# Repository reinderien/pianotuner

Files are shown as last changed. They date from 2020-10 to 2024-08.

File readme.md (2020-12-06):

# Custom Piano Tuner

## Environment

### apt packages

- libasound2-dev (for compilation only)
- libasound2 - underlying ALSA support
- linux-libc-dev - Linux headers for SPI

Remove pulseaudio.

Todo: move to headless mode and blow away a pile of unneeded packages.

### /boot/config.txt

```
# See https://rpf.io/configtxt
dtparam=spi=on

dtoverlay=spi0-1cs

arm_64bit=1

# todo: turn off video
```

### Audio USB device details

`dmesg`:

```
usb 1-1.2: new full-speed USB device number 3 using xhci_hcd
usb 1-1.2: New USB device found, idVendor=0d8c, idProduct=013c, bcdDevice= 1.00
usb 1-1.2: New USB device strings: Mfr=1, Product=2, SerialNumber=0
usb 1-1.2: Product: USB PnP Sound Device
usb 1-1.2: Manufacturer: C-Media Electronics Inc.      
input: C-Media Electronics Inc.       USB PnP Sound Device as /devices/platform/scb/fd500000.pcie/pci0000:00/0000:00:00.0/0000:01:00.0/usb1/1-1/1-1.2/1-1.2:1.2/0003:0D8C:013C.0001/input/input0
hid-generic 0003:0D8C:013C.0001: input,hidraw0: USB HID v1.00 Device [C-Media Electronics Inc.       USB PnP Sound Device] on usb-0000:01:00.0-1.2/input2
```

`lsusb`:

```
Bus 001 Device 003: ID 0d8c:013c C-Media Electronics, Inc. CM108 Audio Controller
```

`arecord -l`:

```
**** List of CAPTURE Hardware Devices ****
card 1: Device [USB PnP Sound Device], device 0: USB Audio [USB Audio]
  Subdevices: 1/1
  Subdevice #0: subdevice #0
```

`arecord -L`:

```
default:CARD=Device
    USB PnP Sound Device, USB Audio
    Default Audio Device
sysdefault:CARD=Device
    USB PnP Sound Device, USB Audio
    Default Audio Device
hw:CARD=Device,DEV=0
    USB PnP Sound Device, USB Audio
    Direct hardware device without any conversions
plughw:CARD=Device,DEV=0
    USB PnP Sound Device, USB Audio
    Hardware device with all software conversions
```

Examine these lines in `/usr/share/alsa/alsa.conf`; the defaults should
correspond to the correct card and device listed above:

```
defaults.ctl.card 1
defaults.pcm.card 1
defaults.pcm.device 0
defaults.pcm.subdevice 0
```

### Audio input test

```
$ arecord -D hw:CARD=Device,DEV=0 -c 1 -f S16_LE -r 48000 -d 1 -v output-test
Recording WAVE 'output-test' : Signed 16 bit Little Endian, Rate 48000 Hz, Mono
Hardware PCM card 2 'USB PnP Sound Device' device 0 subdevice 0
Its setup is:
  stream       : CAPTURE
  access       : RW_INTERLEAVED
  format       : S16_LE
  subformat    : STD
  channels     : 1
  rate         : 48000
  exact rate   : 48000 (48000/1)
  msbits       : 16
  buffer_size  : 24000
  period_size  : 6000
  period_time  : 125000
  tstamp_mode  : NONE
  tstamp_type  : MONOTONIC
  period_step  : 1
  avail_min    : 6000
  period_event : 0
  start_threshold  : 1
  stop_threshold   : 24000
  silence_threshold: 0
  silence_size : 0
  boundary     : 1572864000
  appl_ptr     : 0
  hw_ptr       : 0
```

### Verifying SPI

```
$ raspi-gpio get | grep SPI0
GPIO 9: level=0 fsel=4 alt=0 func=SPI0_MISO pull=DOWN
GPIO 10: level=0 fsel=4 alt=0 func=SPI0_MOSI pull=DOWN
GPIO 11: level=0 fsel=4 alt=0 func=SPI0_SCLK pull=DOWN
```

```
$ lsmod | grep spi
spidev                 24576  0
spi_bcm2835            24576  0
```

```
$ ls -l /dev/spi*
crw-rw---- 1 root spi 153, 0 Dec  5 17:06 /dev/spidev0.0
```

```
# First, guarantee sync; this requires at most two bytes
echo -ne "\x00\x00" > /dev/spidev0.0

# Channel 1: 1V, 205: 0b001_000_00 0b1100_1101
echo -ne "\x20\xCD" > /dev/spidev0.0

# Channel 2: 2V, 410: 0b010_000_01 0b1001_1010
echo -ne "\x41\x9A" > /dev/spidev0.0

# Channel 5: 3V, 614: 0b101_000_10 0b0110_0110
echo -ne "\xA2\x66" > /dev/spidev0.0

# Channel 4: 4V, 26, 0b100_11001
echo -ne "\x99" > /dev/spidev0.0
```

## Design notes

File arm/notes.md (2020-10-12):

## Hardware

The RPI 4 has a:
 
- BCM2711: Quad-core Cortex-A72 ARM v8-A 64-bit (Requires upgrading from
  Raspbian for 64-bit support)
- NEON SIMD extensions are mandatory per core
- VFPv4 Floating Point Unit onboard (per core)
- 32 64-bit FPU registers
- fused multiply-accumulate instructions

## Math

                          N-n-1
We need to compute r(n) = sum_k x(k)*x(k + n)
                          k=0

As the dot product,

    r(n) = x[0:N-n] dot x[n:N]

If there are 2048 samples, an S16 will overflow if the mean is above

    sqrt(2^15 / 2048) = 4

so it can't be done in-place. An equivalent S32 won't overflow until a mean of

    sqrt(2^31 / 2048) = 1024

but overflow becomes a non-issue for BLAS, which requires floats.

## BLAS

We aren't using anything in GSL that BLAS doesn't already have, so use the
latter. The input type is float. The output type can be float or double.

For the dot-product method, vectors will be aliased (overlap). GSL says:

> If the arguments will not be modified (for example, if a function prototype 
> declares them as const arguments) then overlapping or aliased memory regions 
> can be safely used.

BLAS "scalar" dot product is level 1 (vector*vector); we have to loop N times
calling `cblas_sdot` and offsetting the second vector every time.

Level 2 (matrix*vector) would use an "anti-triangular" matrix that is symmetric,
calling `cblas_ssymv`. Unfortunately `lda` does not permit row pitch hacks that
would allow us to reuse a single vector.

Alternatively, for the reversed-triangular case, we could use `cblas_strmv`, but
the same pitch restriction applies. This means that we can't have a row-aliased
matrix, because it doesn't use array-of-array format; it uses a contiguous 
block.

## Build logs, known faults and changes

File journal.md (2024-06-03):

### Dec 20, 2015

I started a rudimentary, software-only piano tuner experiment.

### Dec 21, 2015

Abandoned the software experiment.

### July 4, 2019

I hack together some notes for a possible hardware implementation of a piano
tuner, thinking about:

- Needles for octave, note in octave, tuning in note, volume
- Lamp for power
- Lamps behind needle dials
- Capacitive fade-in for lamps
- Glass or plastic bead in front of power lamp
- Phonograph-style mic pickup
- Clock hands for needles

Initially I assume it'll run a Fast Fourier Transform, and toy with the idea
of using a 
[Texas Instruments LEA](https://www.ti.com/lit/an/slaa720/slaa720.pdf)
(Low-Energy Accelerator). That would be good if we're making 10,000 of these
things, but it would be a steep learning curve.

All of this goes into a Google Doc and then somewhat forgotten about.

### Sept 26, 2020

I found an antique-style wooden box on Facebook Marketplace. It's pretty
clearly one-of-a-kind, and was hand-made in an Egyptian workshop by a late 
relative of the seller. It's perfect.

In around now, plotting starts to solidify for a hardware tuner.

### Sept 28, 2020

Wife orders 
[copper foil](https://www.amazon.ca/gp/product/B0042SWYUA) 
for the horn. I order the 
[USB microphone](https://www.amazon.ca/gp/product/B07VWJ1XB2) 
that will be connected to the Raspberry Pi 4 I have on hand.

### Sept 29, 2020

Orders for more power accessories:
[5V 25W power supply](https://www.amazon.ca/gp/product/B00DECXUD0), 
and a nice little 
[USB-C-to-terminal-block power adapter](https://www.amazon.ca/gp/product/B07R8YPFD7)
to power the Pi without having to jankily connect a cell phone charger on the
inside of the enclosure.

Ordered a handful of gauges, 5Vdc analogue, of various sizes:

[45mm](https://www.ebay.ca/itm/181981812727),
[66mm](https://www.ebay.ca/itm/183445575857)
and
[90mm](https://www.ebay.ca/itm/172695600128).

These are coming from China so I'm expecting it to take forever for them to 
get here, but anything in North America is exhorbitant. The intent is to 
replace the faceplate with a custom one and backlight it if possible.

Order some vintage-style electrical accessories from 
[Vintage Wire & Supply](https://vintagewireandsupply.com). They're relatively
expensive but look incredible.

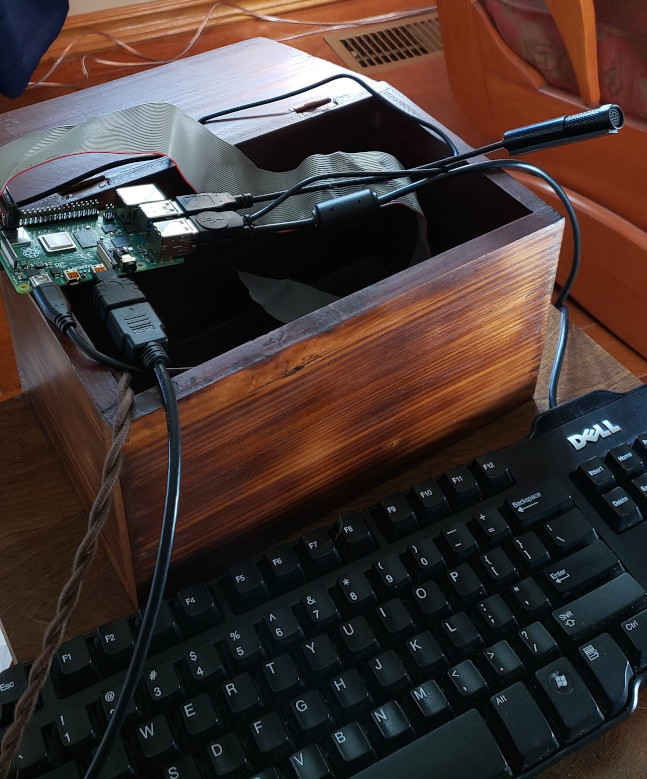
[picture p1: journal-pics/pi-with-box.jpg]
Raspberry Pi sitting outside of the box


Pictured above: temporary keyboard on the bottom; open box (so far unmodified) 
in the middle with the Raspberry Pi board sitting on top of it; USB microphone 
sticking out to the right. The ribbon cable is for a real-time clock that is 
also temporary. On the left you can see the twisted brown cotton vintage-style 
120VAC cord.

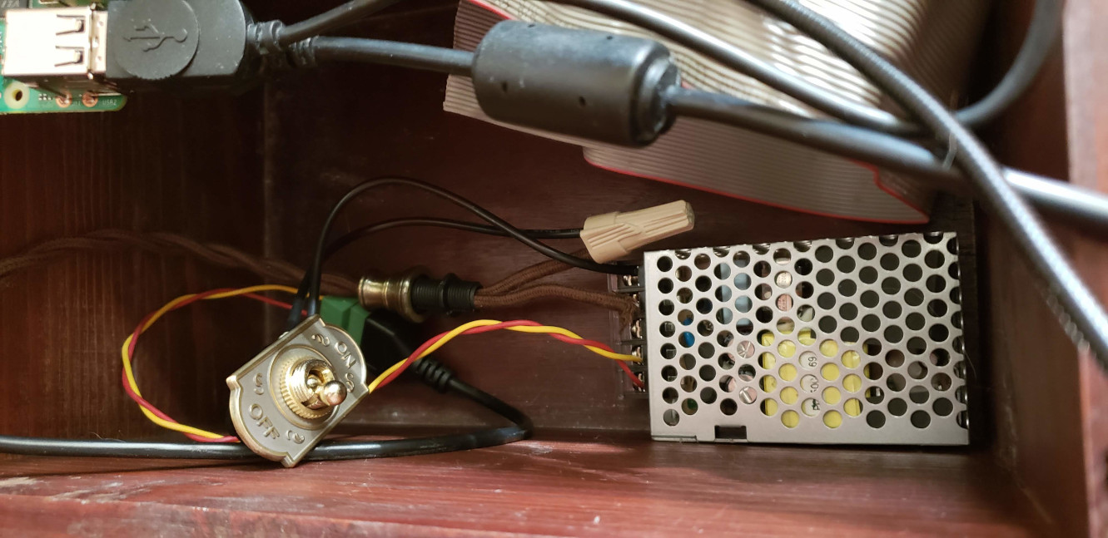
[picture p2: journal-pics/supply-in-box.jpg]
Power components sitting in box


Pictured above: power components sitting in a temporary arrangement in the box. 
Far centre left is the brown 120VAC cord, running to a brass stress relief in 
the middle that will eventually be in the side of the box. Centre is a white 
marette to the switch. Lower left is the antique switch that will be mounted to 
the exterior of the box. Lower right is the MeanWell power supply; more rugged 
and well-ventilated than the typical cell phone charger. The red-yellow cord 
runs 5V from the power supply to a small green terminal block, in turn through a 
USB-C cable to the Raspberry Pi on the upper left.

### Oct 2, 2020

Going on vacation. The wife has let me bring a pile of tech goodies to work on 
this project.

### Oct 3, 2020

Using the same GitHub web page, resuscitate the tuner project, but with 
hardware in mind. The Raspberry Pi, keyboard, mouse, microphone and cell phone
power supply are set up on the coffee table of the cottage, and I have a great
time getting going on development.

### Oct 4, 2020

Start using the Simple Direct Layer for microphone capture on the Raspberry Pi.
Pretty much immediately throw that out the window in favour of the underlying
Advanced Linux Sound Architecture.

### Oct 7, 2020

Research into the best way to detect pitch. Intend on running autocorrelation 
for note detection, in line with the
[findings of Coert Vonk](https://coertvonk.com/sw/embedded/arduino-pitch-detector-13252),
and associated research by
[Brown](http://academics.wellesley.edu/Physics/brown/pubs/acptrv89P2346-P2354.pdf)
and
[Monti](http://193.166.3.2/pub/sci/audio/dafx/2000/profs.sci.univr.it/%257Edafx/Final-Papers/pdf/Monti_DAFX00poster.pdf).

Some of it makes no sense to me so I post on a 
[Digital Signal Processing](https://dsp.stackexchange.com/questions/70736)
forum.

Ordered some Microchip PIC16LF1773 (programmable interrupt controller) from 
Mouser, since DigiKey was nearly out of stock. These devices have a mix of 5- 
and 10-bit unbuffered DACs that can be internally buffered with three op-amps; 
they also support UART, I2C and SPI - so one way or the other they'll 
definitely be able to talk with the Pi.

### Oct 10, 2020

Start using the Gnu Scientific Library with the intent of applying it to the 
autocorrelation work.

### Oct 11, 2020

Throw GSL out the window in favour of ATLAS (Automatically Tuned Linear Algebra 
Software), an implementation of BLAS (Basic Linear Algebra Subprograms).

### Oct 16, 2020

The gauges arrived from China, quicker than I expected! They're wonderful
little devices, fully disassemble-able with two screws on the side, and come
pre-packaged with hardware for the mounting bolts. There's a high-accuracy
resistor in each, and the input impedance is a little over 5k, so the PIC can
definitely handle it.

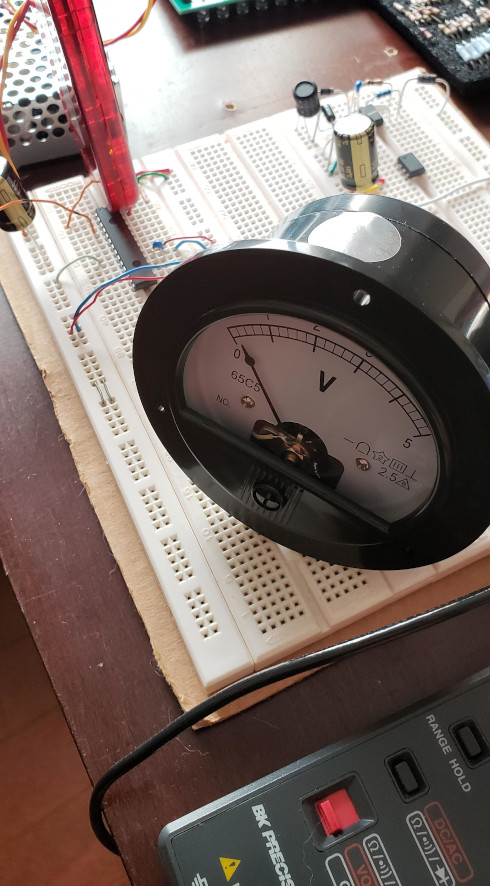
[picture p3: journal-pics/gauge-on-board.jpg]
Gauge sitting on a breadboard


Upper left: chassis of the power supply; with the red PICkit 3 programmer in 
front of it, plugged into the breadboard.

The breadboard has the intended DAC PIC just below the PICkit.

On the gauge itself: the sticker on the top will be discarded; the front 
plastic pane and surrounding cylindrical cover come off with two screws on the 
side (not shown); then the instrument plate comes off with two bolts on the 
front.

### Oct 19, 2020

Start a PIC firmware project to act as a DAC (digital-to-analogue converter) 
for the Raspberry Pi.

### Oct 21, 2020

Start an Eagle schematic to plan out how the DAC will be connected.

### Oct 22, 2020

Parts I still need to dig up or buy:

- Amber LEDs for the gauge backlights
- Perfboard
- Rectangular cable to run from the Pi to header on the perfboard
- A rail-to-rail 0-5V buffer op-amp for the one remaining unbuffered DAC output

I also need to upgrade the Pi to a 64-bit operating system, since I didn't 
realize I had been using a deprecated 32-bit Raspbian.

Also need to write a calibration routine that gives me interquartile range for
the harmonics at various notes.

### Oct 23, 2020

Consider using a nice amber LED for backlights; such as the Lite-On LTL-1CHA with
- 3mm diffusion lens
- 20mA max, 2.1 volts forward
- 60° half-power angle
- Wavelengths: 602 nanometres dominant, 610 nanometres peak

If we use 10mA, we need 270R limiting each LED. For fade-in with a capacitor 
parallel to the LED, and a time constant over 2 seconds, we need a large 
capacitor of ~10mF.

### Oct 24, 2020

The capacitive fade-in option kind of sucks. The capacitors needed are big and 
expensive, and all four could be replaced with a single 40mA MOSFET driven by
PWM from the PIC. Another advantage of PWM would be that it works right away,
where as capacitive charge has to go through a dead zone where the forward 
voltage is below that needed by the LED.

The PIC16F1773 supports 10/16-bit hardware PWM with a bunch of different 
sources. PWMs 3, 4, 5, 6, 9 and 11 all support PPS and at least one of them can
output to each of PORTA/B/C, respectively. Compare/capture/PWM (CCP) modules
1, 2, and 7 likewise can output to at least one of those ports.

The hardware solution would have charged by

    V(t) α 1 - exp(-t/𝜏)
    
with 90% by

    t = -𝜏 ln(1 - 0.9)

If we want 90% in two seconds, 𝜏 ~ 0.8686, and our time expression becomes

    V(t) α 1 - 0.1^(t/2)

A piecewise linear approximation would depend on the derivative:

    dV/dt = 1/𝜏 exp(-t/𝜏)
          = -ln0.1 / 2 * 0.1^(t/2)
    
If we increment 8 of the 16 bits in the duty cycle for a PWM,
the configuration would be

    EN = 1
    MODE = 00 (standard)
    PRIE = 1 (interrupt on period match to update duty)
    PS set to divide between 2^0 and 2^7
    CS either HFINTOSC (16MHz) or LFINTOSC (31kHz) - both sleep-compatible
    OFM = 00 (independent run)

We will be starting DC at 0, DC delta at a high value, and applying a simple
binary exponential decay algorithm on the delta. To find the initial delta
value we need to work backward: at the end of the curve, the delta will only
be 1, representing 2^-8 of full deflection. The last intersection of the exact
and approximate curves is at

    -𝜏 ln(2^-8) ~ 4.817 s
    
At this time, the derivative is

    1/𝜏 * 2^-8 ~ 0.004497

The time it takes to increase 2^-8 is, with an initial tangent,

    2^-8 𝜏 exp(t/𝜏)

which starts as 3.4 ms. If we only did this for one cycle, we could still have
a PWM rate of 295 Hz. Assuming a PR of 0x100, 

    Period = (PWMxPR + 1) * prescale / clock
    prescale = log(16e6 * 2^-8 𝜏 / (2^8 + 1)) / log(2) ~ 7.72 > 7

The slowest prescale for 16-bit PWM is 2^7, which would mean a period value of

    2^-8 𝜏 * 16e6 / 2^7 - 1 ~ 423 > 2^8

which would require carry operations during PWM update. If we go the other way,
disable the prescaler and use LFINTOSC=31kHz,

    2^-8 𝜏 * 31e3 - 1 = 104

`TMR2IE` probably won't work in 10-bit mode, because the timer is cleared on
period match.

It's also worth noting that the transfer function for duty cycle to lumens is 
assumed to be linear but probably isn't.

### Oct 25, 2020

Some of the above will stay true and some won't. The problem with having a
fixed delta update rate is that eventually, the delta would need to be
fractional, and we're only using integer math.

This is a very powerful device; we could pursue any of the following as
alternatives:

- Use 16-bit PWM, interrupt on `PRIF`, increment a soft post-scaler,
  increment `PWMxDC` on post-scale overflow, double post-scale factor every
  140 `PRIF`s
- Use 10/16-bit PWM, short `PWMx` output to `TMR4_clk` input, increment 
  `PWMxDCH` on every `TMR4IF`, short `PWMx` output to `TMR6_clk` input, double 
  `PR4` on every `TMR6IF`
- Use CLC with two internal PWM/CCP inputs, offset by a beat frequency
- Use COG with two internal PCM/CCP inputs, offset by a beat frequency

For the last one, we'd have:

- `COG1CON0`
    - `EN` = 1
    - `CS` = 0b10 (HFINTOSC, sleep-compatible)
    - `MD` = 0b000 (steered PWM)
- `G1RIS9` = 1 (PWM5 for rising)
- `G1FIS10` = 1 (PWM6 for falling)
- `COG1STRA` = 1 (output on steering channel A)

### Oct 27, 2020

Continuing the silliness above, I've posted a 
[detailed solution](https://electronics.stackexchange.com/a/529533/10008).

### Nov 24, 2020

A month, more math and experimentation later, the LED fader is done. As it turns 
out, the luminosity transfer function seems to be visually exponential so I can 
get away with a linear ramp. 

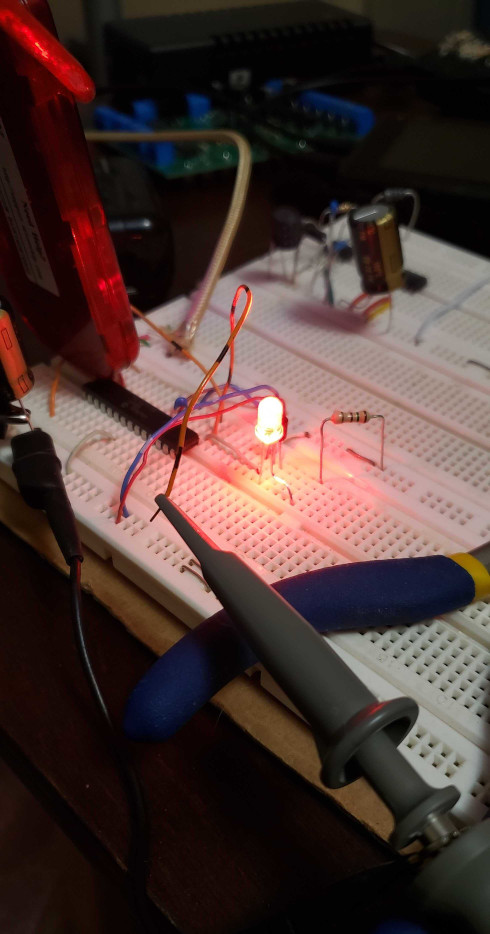
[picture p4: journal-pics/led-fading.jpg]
bright LED


The very bright red LED used in this test will not be used in the final system 
but is working fine nevertheless. This one is so bright that it illuminates my 
ceiling at 20mA.

### Nov 25, 2020

New parts ordered: 

- the protoboard where stuff will get soldered (though-hole only), 
- the nice amber LEDs, 
- some rectangular cables for SPI, and 
- some rail-to-rail operational amplifiers - only one is needed as a buffer for 
  a digital-to-analog converter output; the other outputs have buffers already.

### Nov 26, 2020

Did a rough layout of the digital-to-analog converter circuit as it will be on
the protoboard.

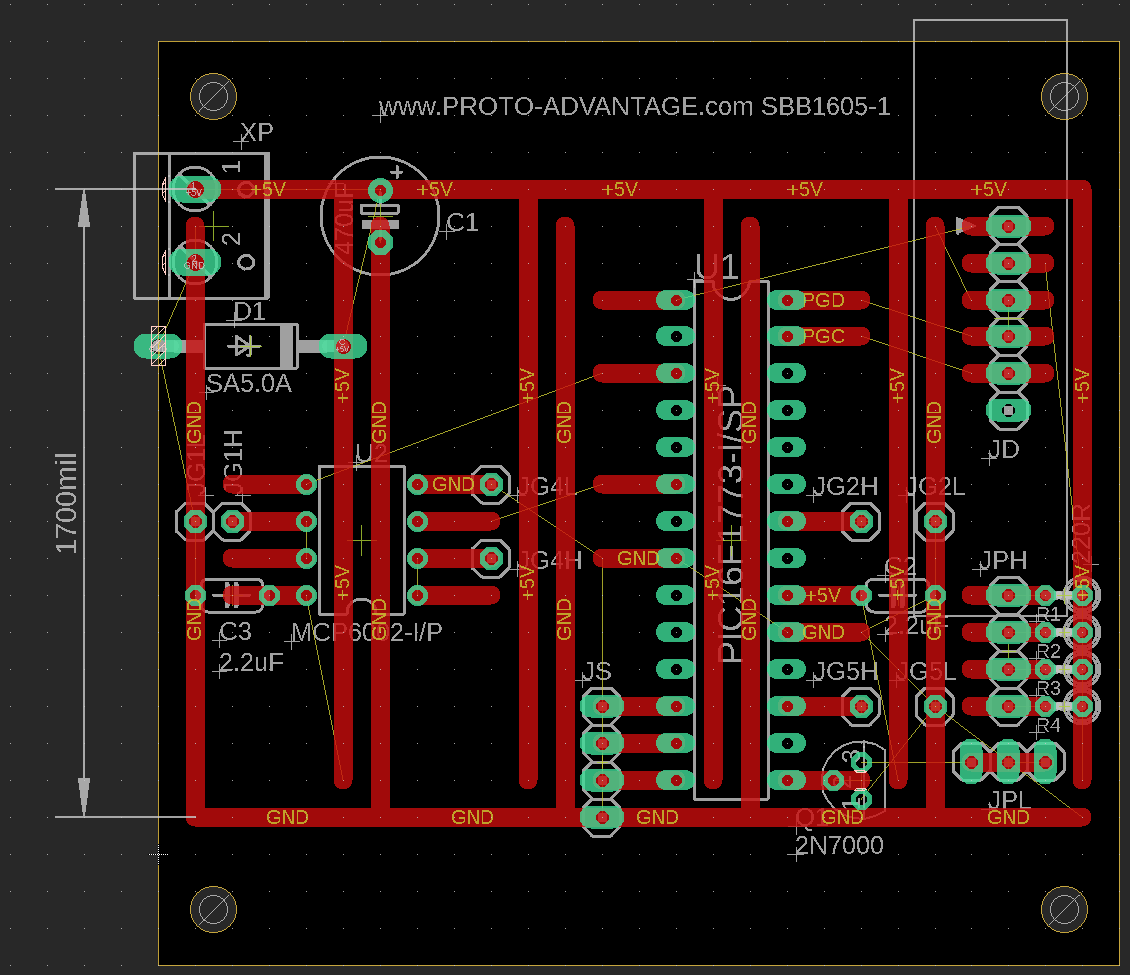
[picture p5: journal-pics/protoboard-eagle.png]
Eagle protoboard layout


- Upper left: the power entry block
- Mid-left: the buffer chip "U2" for gauges. Only one of the two channels is 
  strictly necessary, but use both to offload a tiny bit more current from the 
  MCU and prevent floating.
- Centre: the MCU (microcontroller) "U1" that the Raspberry Pi will talk to, 
  with its SPI (serial port) "JS" on the bottom.
- Lower-right: gauge backlight PWM driving circuit, four-channel
- Upper-right: programming/debug connector "JD".

The red traces are copper on the board's top layer. The thin yellow lines are
ratsnest that I need to wire and solder myself.

### Nov 30, 2020

This `efind` script shows that it's possible to null a fixed, positive offset 
voltage on the MCP6002 operational amplifier I use for DAC buffering.

```python
    Vdd = 5
    Voff = 4.5e-3
    R2 = 0

    def find_r4(R6: float, R5: float, R1: float) -> float:
        return (R5/R6 + 1) * R1 * Voff/Vdd

    def find_r3(R6: float, R5: float, R1: float, R4: float):
        R4R3 = R5/R6 - R4/R1
        if R4R3 == 0:
            return float('inf')
        return R4 / R4R3

    def find_vo(Vi: float, R6: float, R5: float, R1: float, R4: float, R3: float) -> float:
        Vin = Vi*R6/(R6 + R5) + Voff
        I3 = Vin/(R2 + R3)
        I1 = (Vdd - Vin)/R1
        I4 = I3 - I1
        Vo = Vin + R4*I4
        return Vo

    s = Solver(
        (
            Resistor('6', E24, None, 1e6, 10e6),
            Resistor('5', E96, None, 1e3, 10e3),
            Resistor('1', E96, None, 1e6, 10e6),
            Resistor('4', E96, find_r4),
            Resistor('3', E96, find_r3),
        ),
        (
            Output(
                'Vol', 'V', 0,
                partial(find_vo, 0),
            ),
            Output(
                'Voh', 'V', Vdd,
                partial(find_vo, 5),
            ),
        ),
        1e-5,
    )
    s.solve()
    s.print()
```

It outputs:

```
    R6      R5      R1      R4      R3        Vol      Err        Voh      Err
1.5 MΩ 4.42 kΩ 1.13 MΩ 1.02 kΩ  499 kΩ  -13.99 nV -1.4e-08    5.000 V  3.7e-07
1.6 MΩ 6.49 kΩ 1.87 MΩ 1.69 kΩ  536 kΩ  -461.3 nV -4.6e-07    5.000 V  1.9e-06
1.0 MΩ 10.0 kΩ 1.00 MΩ   909 Ω  100 kΩ  -4.500 nV -4.5e-09    5.000 V -5.0e-06
1.0 MΩ 10.0 kΩ 10.0 MΩ 9.09 kΩ 1.00 MΩ  -4.500 nV -4.5e-09    5.000 V -5.0e-06
```

But I won't actually do this nulling, for reasons listed
[here](https://electronics.stackexchange.com/questions/534855).

### December 4, 2020

When my brothers play Path of Exile with me, they have taken to calling its
[crafting workbench](https://pathofexile.gamepedia.com/Crafting_Bench) "[my]
actual workbench" due to its electrified animations. Currently, on the first
day of my latest vacation, my mobile workbench looks like this:

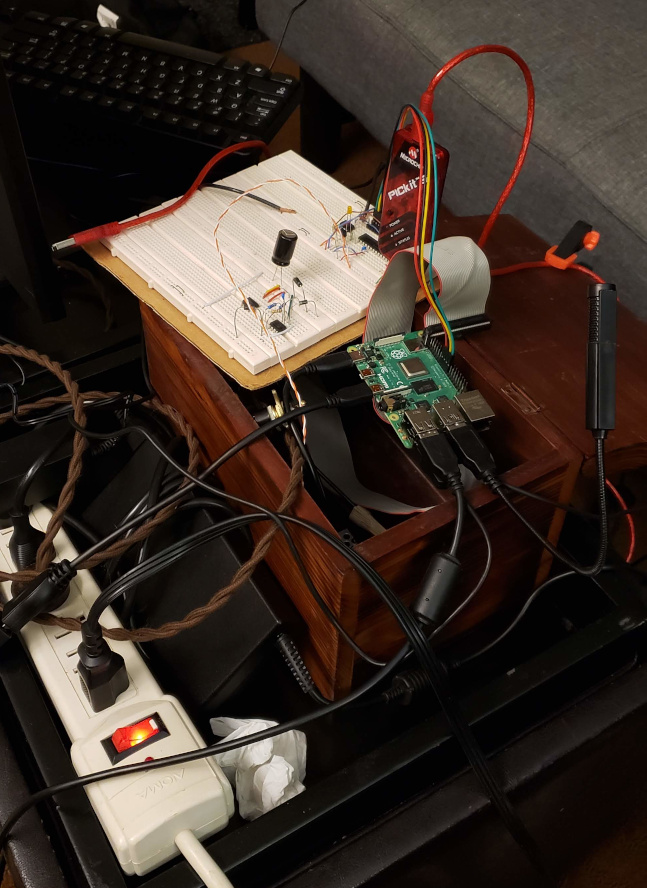
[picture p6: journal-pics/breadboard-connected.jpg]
Breadboard connected


This marks the first time that the breadboard is connected to the Pi via a 
4-conductor wire carrying SPI. The SPI microcontroller firmware was written
last weekend but hasn't been tested yet. The buffer op-amp is connected and
initial gauge tests work. The gauge input posts are left-negative, right-
positive when looking from the front.

I've also (finally) started using a 64-bit OS for the Raspberry Pi 4.

Next is to:

- based on the 
  [documentation](https://www.raspberrypi.org/documentation/hardware/raspberrypi/spi/README.md#software),
  put the SPI module in 8-bit, `SPI_NO_CS` mode
- work off of the Raspberry Pi/Linux
  [SPI test code](https://github.com/raspberrypi/linux/blob/rpi-5.4.y/tools/spi/spidev_test.c)
  
### December 5, 2020
  
If I end up adding a back-illuminated bead for power indication (which now
seems a little redundant to me given that the gauges are already illuminated
on power), one option if I can't find anything better is this thing from
Michael's:

- Item [10402037](https://canada.michaels.com/en/bead-gallery-crystal-faceted-glass-round-beads-18mm/10402037.html)
- 18mm diameter faceted glass
- It's labelled "crystal", though I don't know how far to trust that
  
A very attractive option from the Bead Boutique is their
[quartz "nuggets"](https://thebeadboutiqueon.com/products/22x15mm-faceted-quartz-nugget-beads):

- Natural clear quartz
- 22x15mm "medium focal" size

As for gauge illumination, the LTL-1CHA is way (way, *way*) too dim to be
useful for backlighting. On the next DigiKey order I'll be switching to high-
brightness amber LEDs from Cree. Looking at the gauge interior again, it does
look like a LED mounted at the inner rear of the gauge would need an eyeballed
30 degrees to either side, or 60 degrees total, without some other diffusion
scheme.

### December 12, 2020

The woodworking portion began. I sought some external expertise from my parents
about the best way to cut circular holes for the gauges. I had started with a
drill and then (massive) reciprocating saw, not realizing that we have a jigsaw
("autoscroller") better-suited to the job. All of the gauge holes were then done
by drill, jigsaw, and then dremel sanding to creep up to a snug fit.

The first (gnarly) cuts:

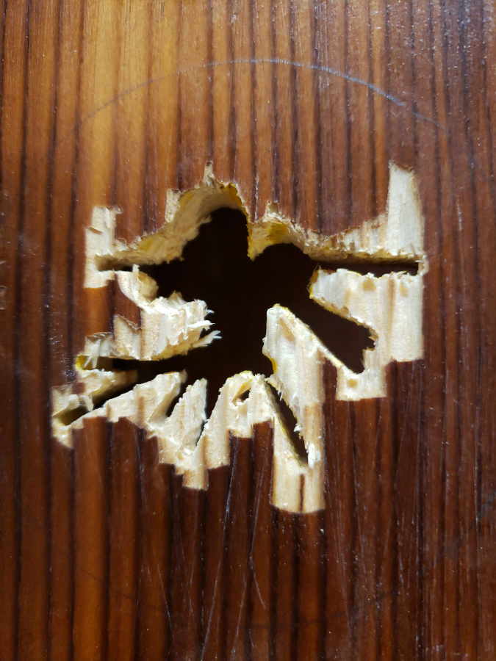
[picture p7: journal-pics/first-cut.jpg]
First cut


This was time-consuming but straightforward. The rear power intake stress relief
was also straightforward. The power indicator was especially lucky: the quartz
teardrop, on its end, fits very well into a hole made by a standard drillbit and
is so snug that it probably won't require glue.

The biggest problem was the power switch. The threaded shaft was too short
compared to the thickness of the wood. A fancy solution would be to recess the
front plate, but I'm not good enough to do that and anyway it wouldn't look as
good as the alternative: ablate a hole for the switch body on the inside of the
box. Given that the box is already assembled and I refuse to disassemble it,
this was a huge pain in the ass and required many passes with an awkwardly-
angled dremel. I got it down to the point where there was barely enough thread
protruding for the front finishing nut to grab, and: good enough.

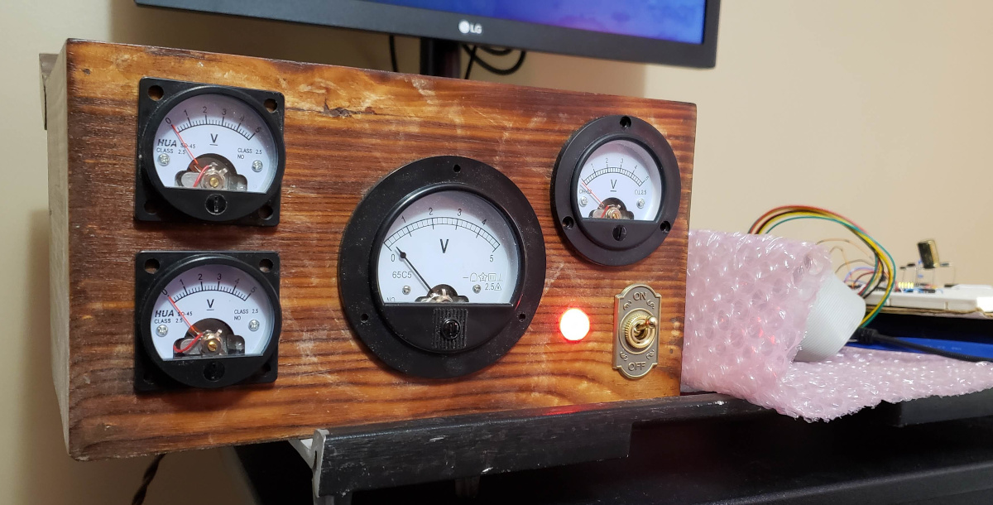
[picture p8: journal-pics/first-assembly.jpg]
First assembly


To do:

- Still need at least one more hole, for the microphone and/or the horn neck
- The wire cleats still need to be attached to the back
- Replacement gauge backlights ordered and installed
- Power indicator dimmed (330R is way too bright) and LED somehow mounted
- Ideally brass screws installed for all gauges
- Maybe re-sand and stain surface? Or leave it looking beat up.

### December 13, 2020

For gauge fastening nuts, they need to be #4-40 (slightly less than 1/8"
diameter shaft),  slightly less than 1/4" diameter head, and at least 3/4" long
if a nut is to be applied on the inside. McMaster-Carr carries
[brass bolts](https://www.mcmaster.com/92443A841/) that would do the job but
apparently some family members have equivalents in stock, so I won't place an
order. (I also considered Acklands-Grainger but it seems that they aren't
shipping anything until the end of January.)

### December 17, 2020

Working moving gauge demo end-to-end. Also, the new backlights are in, and have
a very nice hue and what will certainly be enough brightness. I'm worried about
how narrow the light cone is, but I'll deal with that with a secondary diffuser
if I have to.

### December 19, 2020

Wire cleats, power supply, strain relief and power indicator light all mounted.

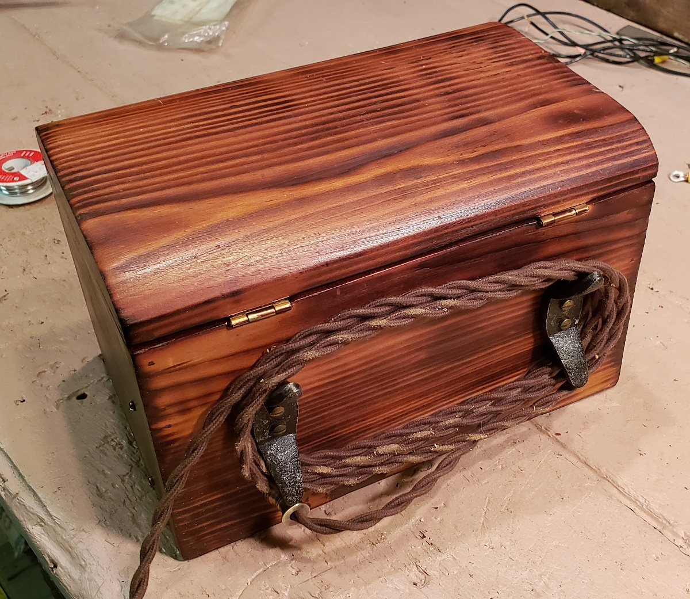
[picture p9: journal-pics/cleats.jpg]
Wire cleats


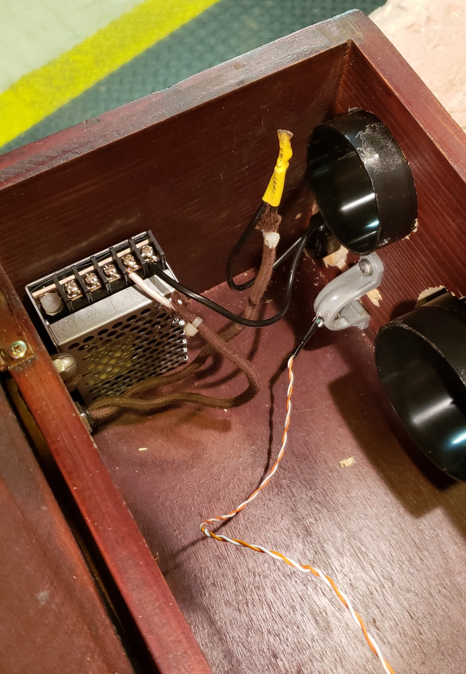
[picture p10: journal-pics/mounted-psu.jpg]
Mounted power supply


The power indicator looks fine with a little over 1mA from a 2.2k resistor. By
contrast, the backlights will need to be fairly bright, close to the
recommended maximum drive current of 30mA through 38 ohms. That resistor had to
be approximated from a parallel 51 and 150 because it's what I have on hand and
doesn't merit a new parts order. With this 38 ohms, the current is shared with
two LEDs in series, which doubles the drive efficiency and allows us to drop
the drive FET - since 60mA is easily within the 100mA tolerated by the PIC's
high-drive mode. In addition to high-drive mode, the PIC port can be put in
open-drain mode (though I found a bug in the Microchip vendor header where some
registers are misnamed or missing, but there's an easy workaround).

Today we started cutting gauge faceplate plastic out of a recycled salad
container. Paper will be glued to the front of these.

### December 20, 2020

Soldering almost done, save some LED wires:

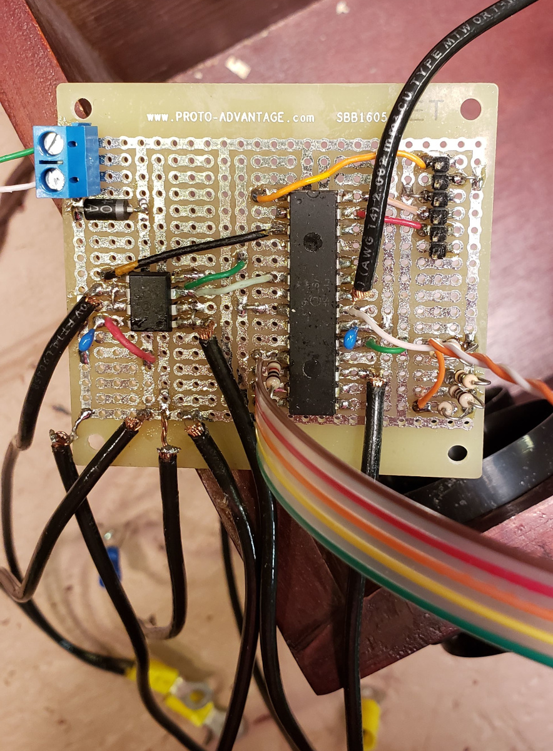
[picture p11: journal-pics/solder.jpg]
Soldered board


I don't like soldering very much, and I'm not great at it, but the board works 
(at least for the PIC and the power LED fade, so far).

### December 22, 2020

Most of the gauge art is done in Gimp. I'm working in 600 DPI, and trying to carefully preserve radial accuracy while substituting gauge scale graphics. Only missing is the decibel scale.

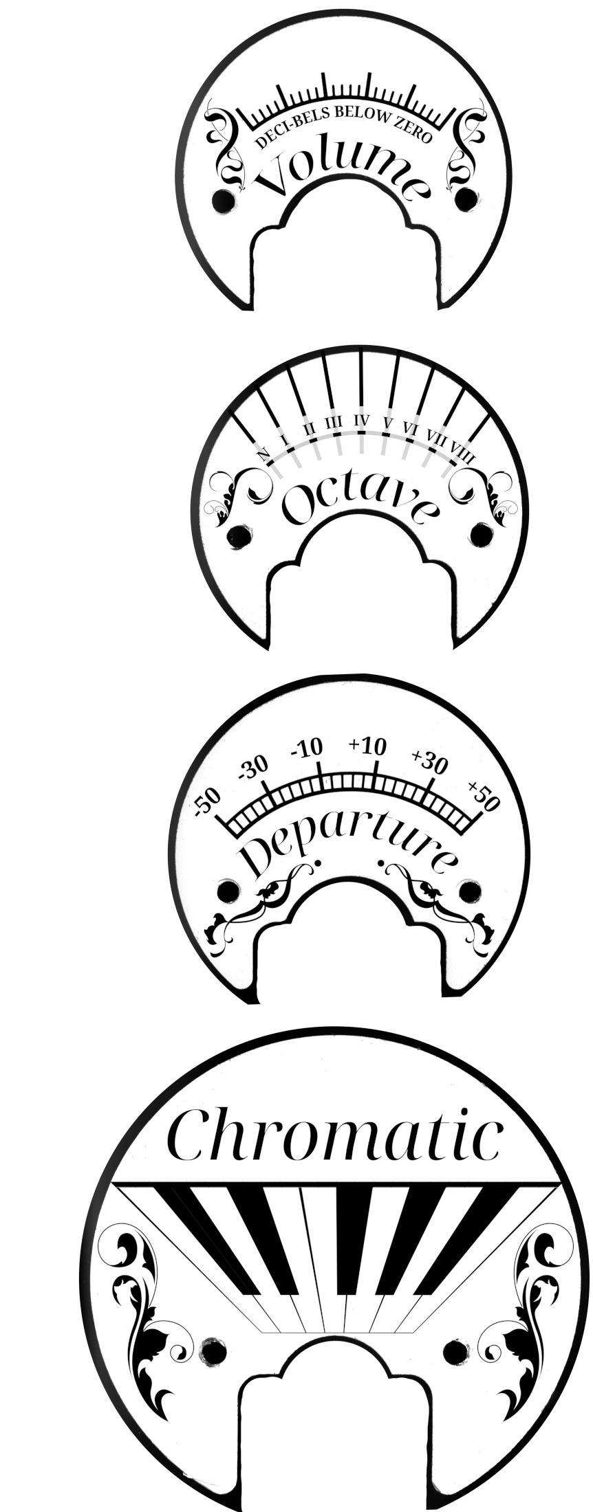
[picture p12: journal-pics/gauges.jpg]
Gauge art


More family help has come in the form of math to accurately identify frequencies:

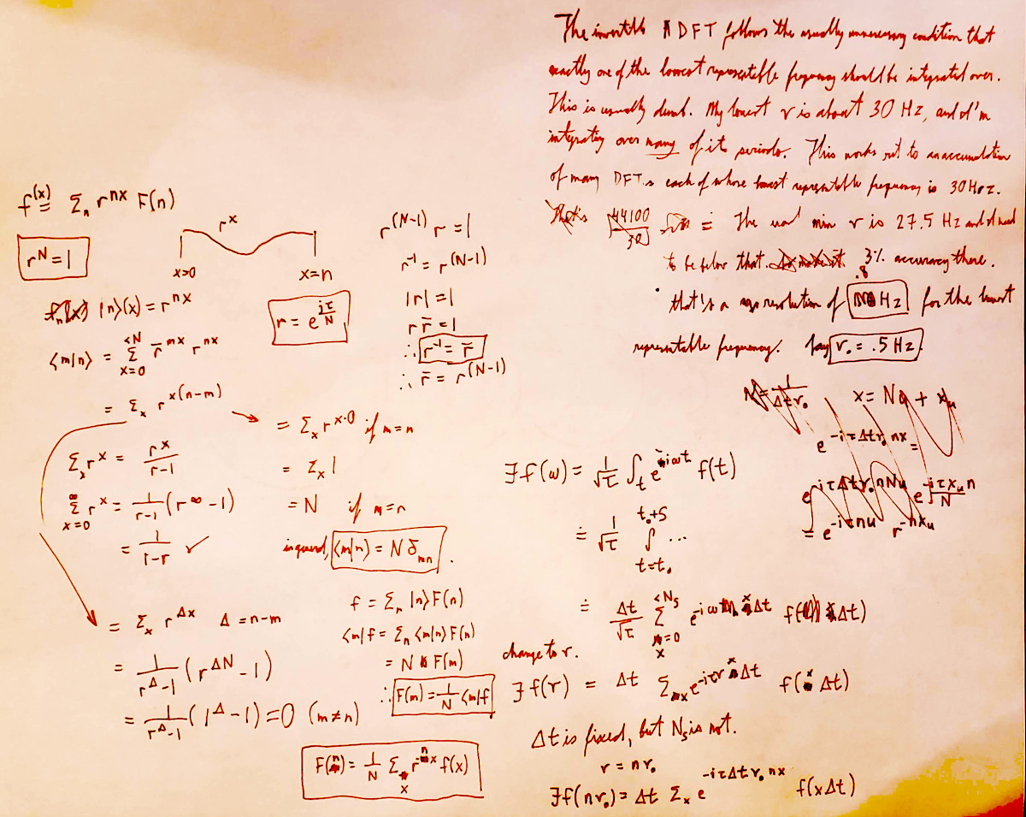
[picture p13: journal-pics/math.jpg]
Audio math


### December 30, 2020

Well, it's been gifted - though it isn't done yet, and I imagine will continue 
to be a labour of love for some time, particularly in software refinement.

Even more family help arrived in the form of pinning down some
[pesky circuit issues](https://electronics.stackexchange.com/questions/539329) 
with a backlight and a gauge. Those seem to have stabilised, so we can finally
focus on the software in more detail.

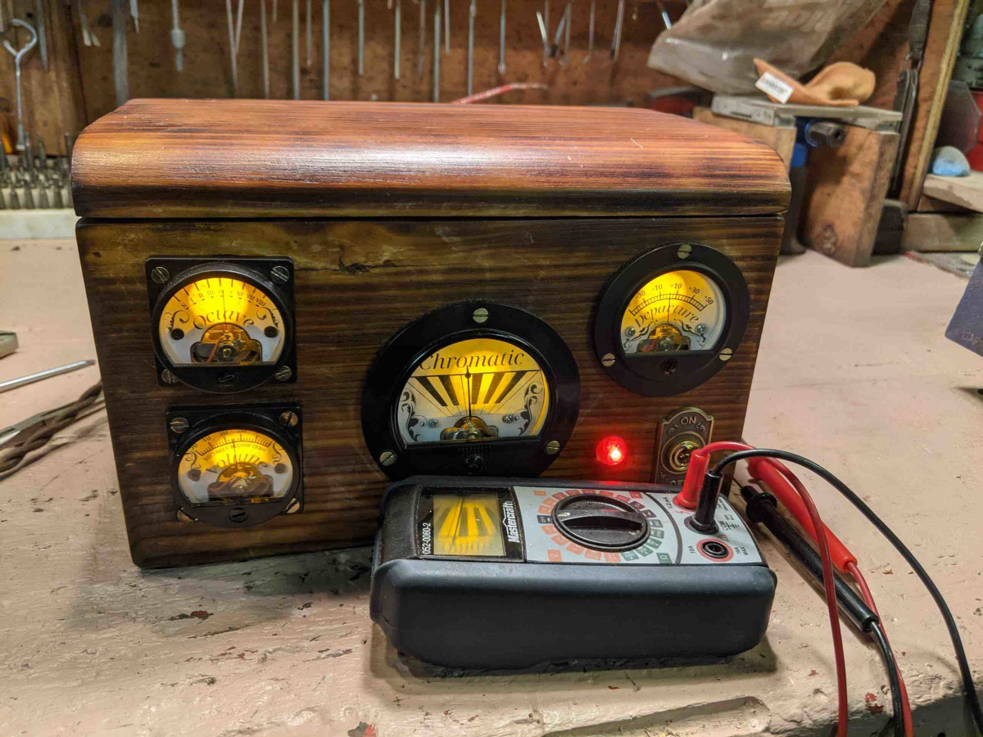
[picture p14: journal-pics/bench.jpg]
Backlit on the bench


As I feared, the light cone is indeed both too sharp and narrow from the LEDs
compared to what I would have preferred, so if I'm feeling extra ambitious or
bored and want to de-solder and de-glue the existing LEDs, I would replace them
with fancy oval ones that have wider viewing angle; or add some diffusion
material.

### April 29, 2021

We're now in the "long tail" of refinements. One of the trickiest bits - fixing
up a gauge winding that was tangled, trimming some gauge surfaces that were
rubbing, and general finagling was needed to get the gauges to move reliably,
and my family was instrumental in getting that done.

Other family help came in the form of a brilliant idea for the diffusion 
problem - simply rough up the LED lenses. This does exactly what it should:

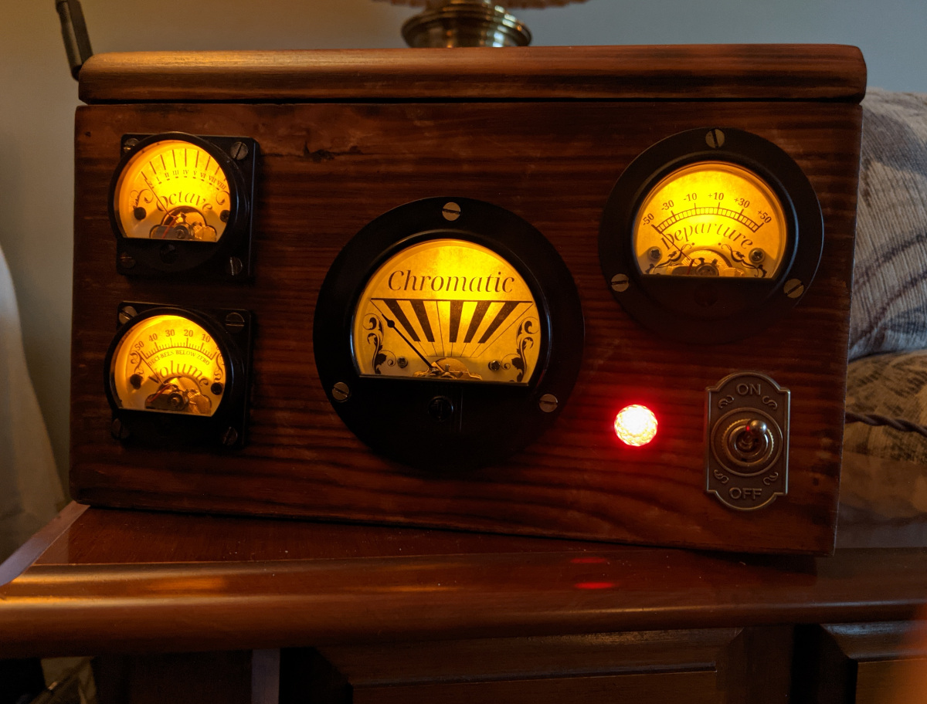
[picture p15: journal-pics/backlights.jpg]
Backlit and diffused


There's a pesky and difficult-to-reproduce microcontroller hang that we might
eventually be able to solve, but in the meantime we're converging on something
that actually works.

### June 5, 2021

The microcontroller issue has probably been
[squashed](https://github.com/reinderien/pianotuner/commit/4da2e95b08d61a83e59ba1c49cfd787ea24f2794).
Previously we'd been putting the microcontroller directly to sleep after detecting an out-of-sync issue, but that was likely causing some following data to be dropped. The safer thing to do is - if we get out-of-sync, stay awake, and don't sleep until (a) we know we're in sync and (b) a complete packet has been received.

### May 21, 2024

After a long period of dormancy, the project got new attention from my brother who reverted the Pi
from Arch Linux to the stock PiOS. The DAC microcontroller is dead. He passed the box, board and
all, to me several weeks ago, then - for a week through today - visited me in person. Whereas it
started off being tuner-themed, the majority of the time ended up being an (extremely productive)
organisation spree. We also visited a local electronics shop to buy connectors and a new, more
spacious board, as well as a comparator to be configured for level shifting.

### June 2, 2024

We needed to buy a level shifter, or at least something to build one, because the RPI and PIC
operate at very different logic levels. I don't remember why, at the time, I deemed it OK to omit
a level shifter, especially given sketchy and very different outputs seemingly exceeding the Pi's
own digital rail; but this time around we need to rule out more things to not fry the poor micro
again.

The comparator we bought is a KA393. After a first prototyping effort failed, I did some more
research and found out that - to my surprise - it's open-collector, which really complicates
things.

Something like the following will have to be used -

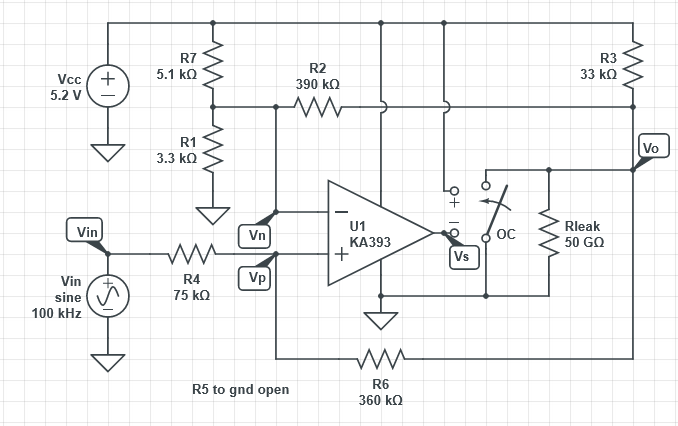
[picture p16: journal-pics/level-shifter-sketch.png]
Level shifter


This needs to meet several requirements:

- Compatibility with the observed, and different, clock and MOSI levels in my notes
- Conversion up to 5V for the PIC
- Noise immunity via hysteresis, which for now I'm assuming will run from 1.2 through 2.8 volts
- Ability to support a resistive pullup without throwing the positive and negative feedback gains
  out of whack
- Pullup not too small, or else it will drag up the comparator's saturation voltage
- Pullup not too large, or else the high voltage won't be high enough for the MCU
- Account for a bias current of 65 nA
- Account for what is now (in the Z-output case) a non-trivial resistive network with no isolation
  between the negative and positive branches
- Account for discretisation error due to E-series resistors
- Don't blow up the comparator by giving it too high a common-mode input

In this case I've given up on pen-and-paper first-principles calculation, and wrote
`level_shifter.py`.

In the interior optimisation loop, it uses `scipy.optimize.root`: a vector-valued root-finding
function which wraps Argonne National Laboratory MINPACK's hybrid implementation of the
[Powell method](https://en.wikipedia.org/wiki/Powell%27s_method). This is used to solve two
[KCL](https://en.wikipedia.org/wiki/Kirchhoff%27s_circuit_laws#Kirchhoff's_current_law_(KCL))
systems, one for the output-Z hysteresis transition case and one for the worst-case common-mode
input. With five voltages as degrees of freedom and the entire resistive network as given, it
solves the trickier network problems in acceptable time - even when given many dozens of vector
dimensions from the outer loop.

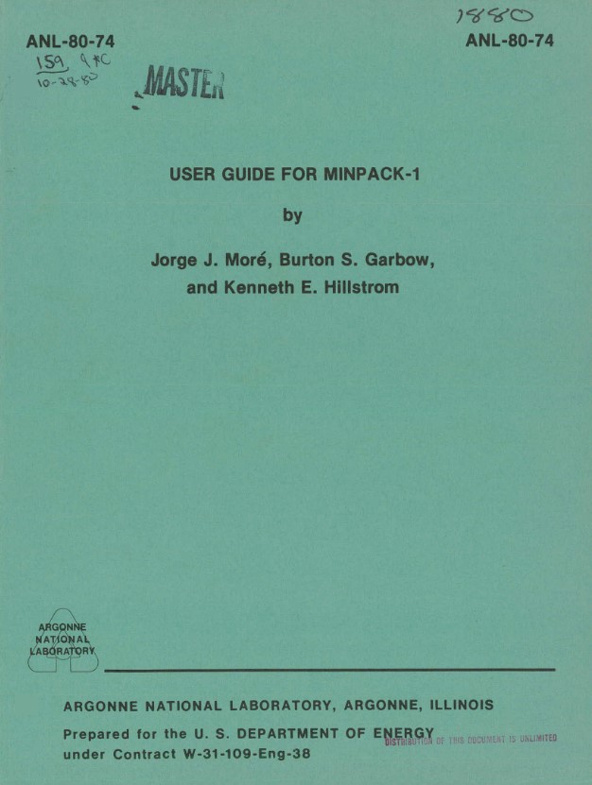
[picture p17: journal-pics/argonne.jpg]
MINPACK


The outer loop needs to be MINLP - mixed-integer nonlinear programming. This stage of the
optimisation needs to be discrete (integral) because of the
[E24 series](https://en.wikipedia.org/wiki/E_series_of_preferred_numbers#Lists); I'd prefer not to
buy exotic resistances from the internet. It's nonlinear because both several voltages and all of
the resistances are unknown, and they multiply with each other. I only know two free solvers. The 
first is `scipy.optimize.differential_evolution` and the second is
[APOPT](http://apopt.com/) as wrapped by [GEKKO](https://gekko.readthedocs.io/en/latest/). I use
the former for convenience. It's an implementation of a 1997 Storn-Price stochastic population
method and does support bounded integral variables. It's slow, but that's fine.

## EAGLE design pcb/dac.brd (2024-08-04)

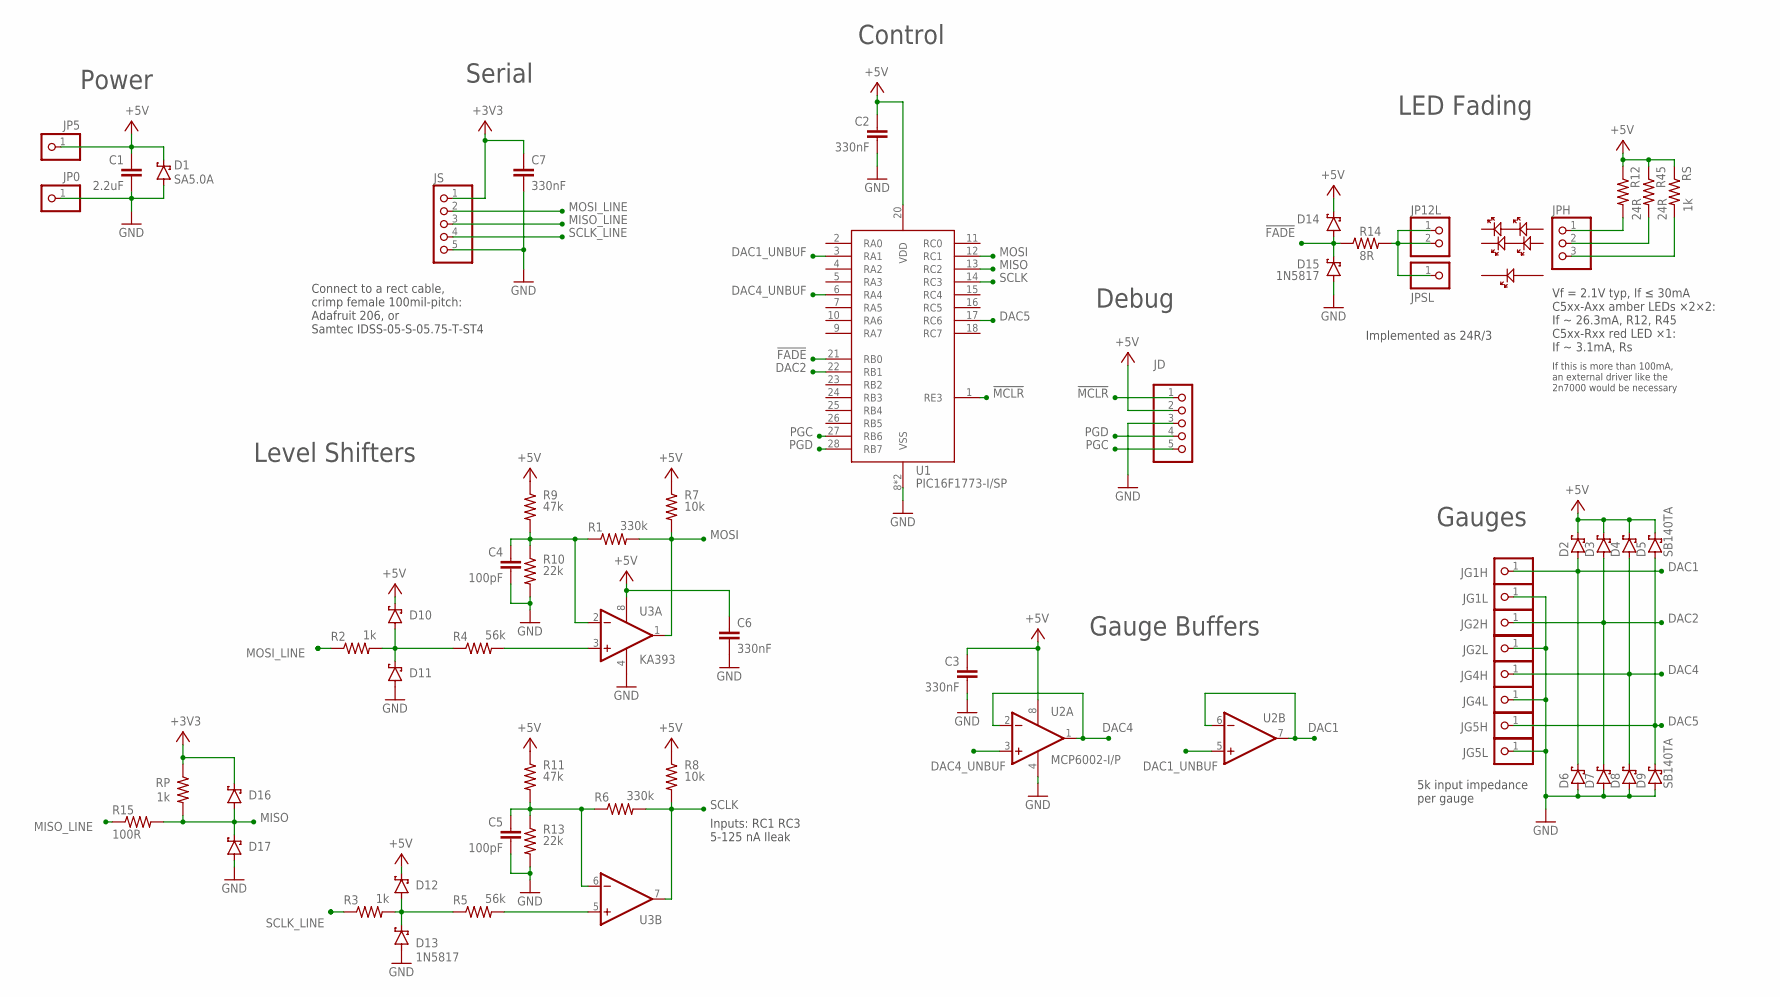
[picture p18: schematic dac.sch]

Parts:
C1: 2.2uF; C050-024X044
C2, C3, C6, C7: 330nF; C050-024X044
C4, C5: 100pF; C050-024X044
D1: SA5.0A; ZDIO-2.5
D2, D3, D4, D5, D6, D7, D8, D9: SB140TA; DO41-7.6
D10: 1N5817-H76; DO41-7.6
D11: 1N5817-V; ZDIO-2.5
D12, D16, D17: 1N5817-T; DO41-7.6
D13: 1N5817; DO41-10
D14, D15: 1N5817; ZDIO-2.5
JD: PINHD-1X5; 1X05
JG1H, JG1L, JG2H, JG2L, JG4H, JG4L, JG5H, JG5L: PINHD-1X1; 1X01
JP0, JP5: PINHD-1X1; 1X01
JP12L: PINHD-1X2; 1X02
JPH: PINHD-1X3; 1X03
JPSL: PINHD-1X1; 1X01
JS: PINHD-1X5; 1X05
R1, R6: 330k; 0207/2V
R2: 1k; 0204/7
R3: 1k; 0207/10
R4: 56k; 0207/10
R5: 56k; 0207/12
R7, R8: 10k; 0207/2V
R9: 47k; 0207/7
R10, R13: 22k; 0207/5V
R11: 47k; 0207/5V
R12, R45: 24R; 0207/2V
R14: 8R; 0207/15
R15: 100R; 0207/10
RP: 1k; 0207/5V
RS: 1k; 0207/2V
U1: PIC16F1773-I/SP; DIL28-3
U2: MCP6002-I/P; DIL08
U3: KA393; DIL08

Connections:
!FADE: D14.A, D15.C, R14.1, U1.21 (RB0)
!FADE_PROT: JP12L.1, JP12L.2, JPSL.1, R14.2
!MCLR: JD.1, U1.1 (RE3)
+3V3: C7.1, D16.C, JS.1, RP.1
+5V: C1.1, C2.1, C3.1, C6.1, D1.C, D2.C, D3.C, D4.C, D5.C, D10.C, D12.C, D14.C, JD.2, JP5.1, R7.1, R8.1, R9.1, R11.1, R12.1, R45.1, RS.1, U1.20 (VDD), U2.8 (V+), U3.8 (V+)
DAC1: D2.A, D6.C, JG1H.1, U2.6 (-IN), U2.7 (OUT)
DAC1_UNBUF: U1.3 (RA1), U2.5 (+IN)
DAC2: D3.A, D7.C, JG2H.1, U1.22 (RB1)
DAC4: D4.A, D8.C, JG4H.1, U2.1 (OUT), U2.2 (-IN)
DAC4_UNBUF: U1.6 (RA4), U2.3 (+IN)
DAC5: D5.A, D9.C, JG5H.1, U1.17 (RC6)
GND: C1.2, C2.2, C3.2, C4.2, C5.2, C6.2, C7.2, D1.A, D6.A, D7.A, D8.A, D9.A, D11.A, D13.A, D15.A, D17.A, JD.3, JG1L.1, JG2L.1, JG4L.1, JG5L.1, JP0.1, JS.5, R10.2, R13.2, U1.8 (VSS), U1.19 (VSS), U2.4 (V-), U3.4 (V-)
LED1: JPH.1, R12.2
LED2: JPH.2, R45.2
LEDSUP: JPH.3, RS.2
MISO: D16.A, D17.C, R15.2, RP.2, U1.13 (RC2)
MISO_LINE: JS.3, R15.1
MOSI: R1.2, R7.2, U1.12 (RC1), U3.1 (OUT)
MOSI_LINE: JS.2, R2.1
MOSI_N: C4.1, R1.1, R9.2, R10.1, U3.2 (-IN)
MOSI_P: R4.2, U3.3 (+IN)
MOSI_PROT: D10.A, D11.C, R2.2, R4.1
PGC: JD.5, U1.27 (RB6)
PGD: JD.4, U1.28 (RB7)
SCLK: R6.2, R8.2, U1.14 (RC3), U3.7 (OUT)
SCLK_LINE: JS.4, R3.1
SCLK_N: C5.1, R6.1, R11.2, R13.1, U3.6 (-IN)
SCLK_P: R5.2, U3.5 (+IN)
SCLK_PROT: D12.A, D13.C, R3.2, R5.1

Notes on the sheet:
5k input impedance per gauge
Connect to a rect cable, crimp female 100mil-pitch: Adafruit 206, or Samtec IDSS-05-S-05.75-T-ST4
Vf = 2.1V typ, If ≤ 30mA C5xx-Axx amber LEDs ×2×2: If ~ 26.3mA, R12, R45 C5xx-Rxx red LED ×1: If ~ 3.1mA, Rs
Gauges
Gauge Buffers
LED Fading
Serial
Debug
Power
Control
If this is more than 100mA, an external driver like the 2n7000 would be necessary
Inputs: RC1 RC3 5-125 nA Ileak
Level Shifters
Implemented as 24R/3

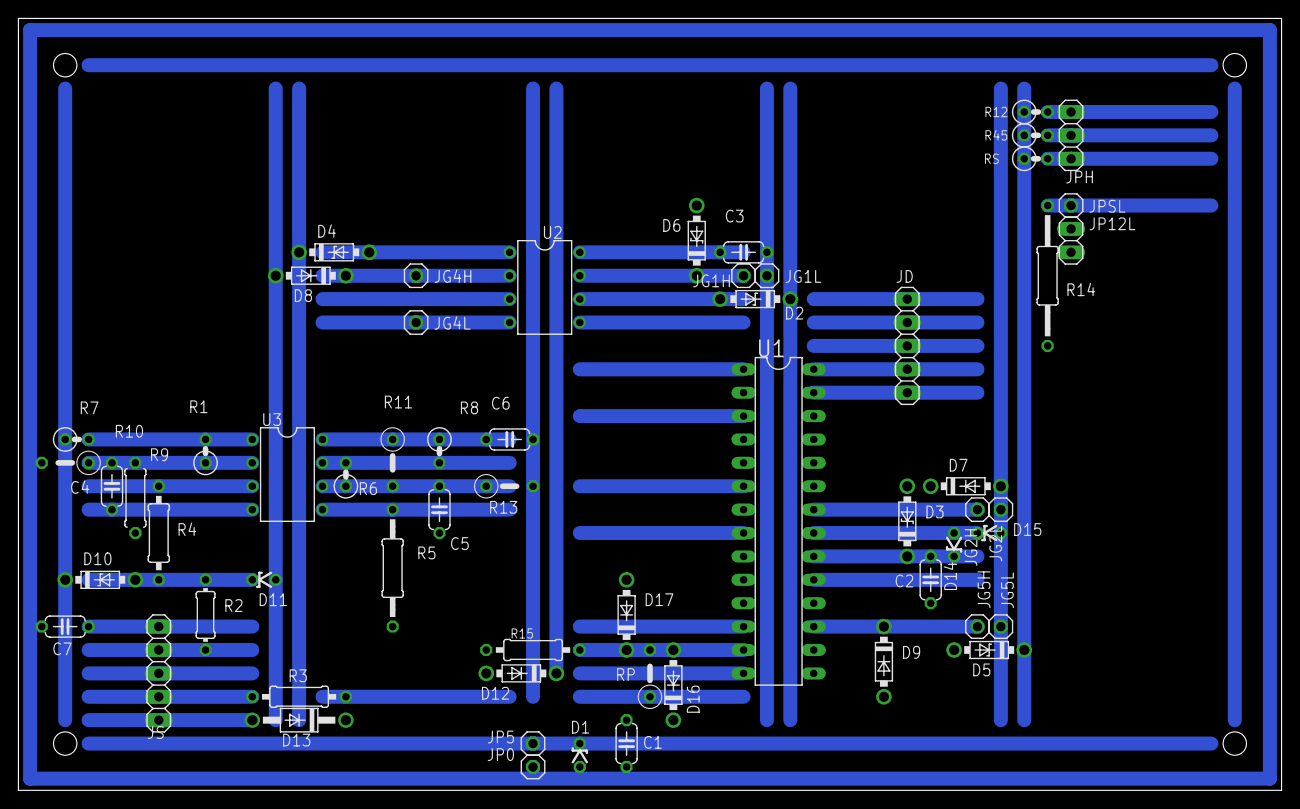
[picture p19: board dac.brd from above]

Board: 2 copper layers, 137.2 x 83.8 mm, 60 parts (0 on the bottom side), 29 nets.

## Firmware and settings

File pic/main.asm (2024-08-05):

#include <xc.inc>
#include "receive.inc"


; CONFIG1
#if build_for_debug==1
    config WDTE=OFF     ; Mandatory for debug: watchdog disabled
    config PWRTE=OFF    ; Power-up timer disabled
#else
    config WDTE=ON      ; Enable watchdog
    config PWRTE=ON     ; Power-up timer enabled
#endif
    config FOSC=INTOSC  ; RA7 has I/O. High-freq intern osc (HFINTOSC) used.
    config MCLRE=ON     ; Memory clear enabled, weak pull-up enabled
    config CP=OFF       ; Code protection off
    config BOREN=ON     ; Brown-out reset enabled
    config CLKOUTEN=OFF ; RA6 has I/O, no clock out
    config IESO=OFF     ; No internal-external clock switchover
    config FCMEN=OFF    ; No fail-safe clock monitoring
    
; CONFIG2
    config WRT=ALL      ; All flash memory self-writes disabled
    config PPS1WAY=ON   ; Peripheral pin select only unlocked once
    config ZCD=OFF      ; Zero-crossing detect disabled by default
    config PLLEN=ON     ; Enable 4x phase-locked loop for internal osc
    config STVREN=ON    ; Stack over/underflow reset enabled
    config BORV=HI      ; Brown-out threshold is 2.7V typ
    config LPBOR=ON     ; Low-power brown-out reset enabled
    ; leave DEBUG up to the programmer
    config LVP=OFF      ; Low-voltage programming disabled
    
    
; If RAM is needed - which it currently isn't, outside of SFRs
; psect variables, class=COMMON, space=SPACE_DATA, delta=1, noexec
; some_var:
    ; ds 1
    
    
; A labelled program section (psect) that does not require ROM paging
#define psect_common class=NEARCODE, space=SPACE_CODE, delta=2
code_psect macro name,optims
#if build_for_debug==1
    psect psect_&name, psect_common
#else
    psect psect_&name, psect_common, optim=optims
#endif
    name:
endm

code_psect por_vec
    ; Oscillator config
    banksel OSCCON  ; 1
    ; IRCF  INTOSC  PRIMUX  PLLMUX  SCS    FOSC
    ; 0111  500kHz       1       0   00  500kHz
    bcf IRCF0
    ; 0110  250kHz       1       0   00  250kHz
    bsf IRCF3
    ; 1110    8MHz       1       1   00   32MHz
    ; At this point, everything should become "ready": MFIOFR, PLLR, HFIOFR;
    ; HFINTOSC PLL should lock within 2% (HFIOFL); 
    ; and it should stabilise within 0.5% (HFIOFS).
    goto init
 
code_psect isr_vec
    ; Unused; interrupts are used to wake up main
    retfie
    
code_psect init
    ; OSCCON and PIEx share bank 1 - set the latter two in sequence here
    ; TRIS could be done this way too but the order doesn't suit this right now
    
init_watchdog:
    banksel WDTCON  ; 1
    ; 8 second watchdog expiry
    movlw (0b01101 << WDTCON_WDTPS_POSN) | (0 << WDTCON_SWDTEN_POSN)
    movwf WDTCON
    
select_interrupts:
    banksel PIE1  ; 1
    bsf TMR2IE  ; Fade disable timer
    bsf SSP1IE  ; SPI receive
    
init_ports:
    ; RA1: ana out OPA1OUT (DAC1)
    ; RA4: ana out DAC4
    ; RB0: dig out COG1A
    ; RB1: ana out OPA2OUT (DAC2)
    ; RB6: dig in  ICSPCLK
    ; RB7: dig in  ICSPDAT
    ; RC1: SDI (MOSI)
    ; RC2: SDO (MISO)
    ; RC3: SCK
    ; RC6: ana out OPA3OUT (DAC5)
    ; RE3: dig in  MCLR
    ; Unused pins ana in weak pullup to 1.
    ; Leave slew rate limitation enabled.
    ; Enable WPUEN for unused inputs.
    
    ; Tristate default is input. Before setting any outputs, configure the other
    ; port properties.
    
    ; Unused or active-low lines set to 1, DAC and PGx set to 0
    banksel LATA  ; 2
    movlw 0b11101101
    movwf LATA
    movlw 0b00111101
    movwf LATB
    movlw 0b10111111
    movwf LATC
    
    ; The only analogue pins are for DAC/OPA, but we also disable the digital
    ; buffers for unused inputs by setting them to analogue. That only leaves
    ; FADE, PG and SPI as digital.
    banksel ANSELA  ; 3
    movlw 0b11111111
    movwf ANSELA
    movlw 0b00111110
    movwf ANSELB
    movlw 0b11110001
    movwf ANSELC
    
    ; Weak pullups on unused ports
    banksel WPUA  ; 4
    movlw 0b11101101
    movwf WPUA
    movlw 0b00111100
    movwf WPUB
    movlw 0b10110001
    movwf WPUC

    banksel ODCONB  ; 5
    ; Open drain for LED fade.
    bsf ODB0
    ; To do a simple level-shift from our 5.2V to the Rpi's 3.3V on MISO, we
    ; add an external pullup to its 3.3V pin and put MISO on RC2 in open-drain
    bsf ODC2

    ; All Schmitt trigger levels.
    ;  ST in: 1.04-4.16
    ;    out: 0.60-4.50
    banksel INLVLA  ; 7
    comf INLVLA  ; Default TTL; switch to ST
    comf INLVLB  ; Default TTL; switch to ST
    comf INLVLC  ; Default TTL; switch to ST

    ; Enable high drive mode (<100 mA sink)
    banksel HIDRVB  ; 8
    bsf HIDB0
    
    ; Needed for WPUA-C above to take effect
    banksel OPTION_REG  ; 1
    bcf nWPUEN
    
    ; Tristates
    banksel TRISA  ; 1
    movlw 0b11101101
    movwf TRISA
    movlw 0b11000000
    movwf TRISB
    movlw 0b00001010
    movwf TRISC
    
init_pps:
    ; RB0: COG1A
    ; RC1: SDI (MOSI)
    ; RC2: SDO (MISO)
    ; RC3: SCK
    banksel RC2PPS  ; 29
    movlw 0b100011  ; SDO
    movwf RC2PPS
    movlw 0b000101  ; COG1A
    movwf RB0PPS
    
    banksel PPSLOCK  ; 28
    movlw 0b010001  ; RC1
    movwf SSPDATPPS
    movlw 0b010011  ; RC3
    movwf SSPCLKPPS
    
    movlw 0x55
    movwf PPSLOCK
    movlw 0xAA
    movwf PPSLOCK
    bsf PPSLOCKED
    
init_fade_cog:
    ; Complementary waveform generator setup to output linear duty cycle growth
    ; based on beat frequency between PWM5 and PWM6. Output goes to a FET driver
    ; on the low side of all backlight LEDs.
    banksel COG1CON0  ; 13
    bsf G1RIS9   ; PWM5 for rise
    bsf G1FIS10  ; PWM6 for fall
    bsf G1STRA   ; Steering out on channel A
    bsf G1POLA   ; Active-low
    bsf G1ASDAC1 ; Logic out if shutdown
    bcf G1ASDAC0 ; Low out if shutdown
    bsf G1CS1    ; Clocked by HFINTOSC
    
    ; Blanking is possible: we only care about events after a minimum period
    ; of 0.9/200Hz=4.5ms. At 16MHz and 6 bits, blanking time maxes out at
    ; (2**6-1)/16MHz = 3.9us. Not even worth it.
    
    bsf G1EN     ; Enable
    
init_fade_pwm:
    ; Beat frequency is chosen between these two PWM modules for a linear DC
    ; from 0 to 100%
    banksel PWM5CON  ; 27
    
    ; HFINTOSC/2**1 = 8 MHz
    movlw (1 << PWM5CLKCON_PS_POSN) \
     | (0b01 << PWM5CLKCON_CS_POSN)
    movwf PWM5CLKCON
    movwf PWM6CLKCON
    
    ; set period = (PWM5PR + 1)*PS / 16MHz
    ; for 200Hz, PS=2, PR5 = 39,999 = 0x9C3F
    
    ; reset period = (PWM6PR + 1)*PS / 16MHz
    ; 5s = tset**2/(treset - tset)
    ; treset - tset = 5us
    ; freset ~ 199.8 Hz
    ; PS=2, PR6 = 40,039 = 0x9C67
    
    movlw 0x9C
    movwf PWM5PRH
    movwf PWM6PRH
    movlw 0x3F
    movwf PWM5PRL
    movlw 0x67
    movwf PWM6PRL
    
    ; 0 phase, 0 offset
    clrf PWM5PHL
    clrf PWM5PHH
    clrf PWM5OFL
    clrf PWM5OFH
    clrf PWM6PHL
    clrf PWM6PHH
    clrf PWM6OFL
    clrf PWM6OFH
    
    ; Minimal duty cycle for both
    movlw 1
    movwf PWM5DCL
    movwf PWM6DCL
    clrf PWM5DCH  
    clrf PWM6DCH
    
    ; Since the falling COG input block is active-low,
    ; PWM6 needs to have its polarity inverted
    bsf PWM6POL
    
    ; Arm-load PWM registers
    bsf PWM5LD
    bsf PWM6LD
    
    ; To enable 5 and 6 at the same time, use mirror registers
    movlw PWMEN_MPWM5EN_MASK \
        | PWMEN_MPWM6EN_MASK
    movwf PWMEN

init_fade_timer:
    banksel T2CON  ; 9
    
    ; We can't use one-shot mode because it doesn't respect the postscaler
    ; LFINTOSC=31kHz
    bsf T2CS2
    ; For 8 bits, 31kHz, 5s, prescale=2**7, postscale=5: tmr ~ 242
    movlw 242
    movwf T2PR
    
    ; On, prescale=2**7, postscale=5
    movlw T2CON_ON_MASK \
        | (7 << T2CON_CKPS_POSN) \
	| ((5 - 1) << T2CON_OUTPS_POSN)
    movwf T2CON
    
init_gauge_dac:
    ; DAC*OUT1 available on pins; four DACs can be internally
    ; buffered through three op-amps:
    ; dac    1   4   2   3   5   7
    ; port RA2 RA4 RA5 RB2 RC0 RC1
    ; pin    4   6   7  23  11  12
    ; oa1    *   *   *   *
    ; oa2    *   *   *   *
    ; oa3                    *   *
    ; bits  10   5  10   5  10   5
    banksel DAC1CON0  ; 11
    ; Start off with all gauges halfway; other bits start as 0
    bsf DAC1REF9 ; 512/1024
    bsf DAC2REF9 ; 512/1024
    bsf DAC4REF4 ; 16/32
    bsf DAC5REF9 ; 512/1024
    ; The 10-bit double-buffers need explicit load
    movlw DACLD_DAC1LD_MASK \
        | DACLD_DAC2LD_MASK \
	| DACLD_DAC5LD_MASK
    movwf DACLD
    ; Only the 5-bit DAC4 will be exposed unbuffered.
    bsf DAC4OE1
    ; Enabled; right-justified; Vdd+; Vss-
    bsf DAC1EN
    bsf DAC2EN
    bsf DAC4EN
    bsf DAC5EN
    
init_gauge_opamp:
    banksel OPA1CON  ; 10
    movlw 0b0010 ; DAC1
    movwf OPA1PCHS
    movlw 0b0011 ; DAC2
    movwf OPA2PCHS
    movlw 0b0010 ; DAC5
    movwf OPA3PCHS
    ; OPACON: enabled, unity gain, no overrides
    movlw OPA1CON_OPA1EN_MASK | OPA1CON_OPA1UG_MASK
    movwf OPA1CON
    movwf OPA2CON
    movwf OPA3CON
    
init_rpi_spi:
    ; MSSP SPI child mode on all-PPS selected pins
    ; SCK, SDI (MOSI), SDO (MISO)
    banksel SSP1CON1  ; 4

    ; Data read on low-to-high clock
    bsf CKE

    ; SPI child mode, SS pin control disabled
    ; clock = SCK pin with idle-low polarity
    movlw SSP1CON1_SSPEN_MASK | 0b0101
    movwf SSP1CON1
    
    ; TSCHSCK input high (also low) time, child mode, >= Tcy + 20 (ns)
    ; Instruction cycle time Tcy = 125 ns
    ; Sclk <= 3.45MHz from the Pi

enable_interrupts:
    ; Every interrupt we use is on a "peripheral"
    bsf PEIE  ; cross-bank
    ; We don't actually need an interrupt vector; we just use interupts to wake
    ; bsf GIE
    
main:
    banksel PIR1  ; 0
fade_wait:
    sleep
    btfss TMR2IF
    bra fade_wait
    
fade_disable:
    ; Per 27.6.1, regardless of EN, if shutdown is active, output will take the
    ; "shutdown override" value from ASDAC - which we've set to 1
    banksel COG1CON0  ; 13
    bsf G1ASE  ; Auto-shutdown enable
    bcf G1EN   ; Disable the COG
    banksel PWMEN  ; 27
    clrf PWMEN ; Disable PWM5, 6
    banksel T2CON  ; 9
    bcf T2ON   ; Disable the timer (manual due to free-run mode) 
    banksel PIE1  ; 1
    bcf TMR2IE ; Disable timer int
    banksel PIR1  ; 0
    bcf TMR2IF ; Clear the timer int flag
    
rx_reset:
    ; Reset the receiver state to here if something smells
    dac_10b_rx 1
    dac_10b_rx 2
    dac_10b_rx 5
    dac_5b_rx 4
    
    ; until we get a serial interrupt for the first byte of the next packet
    sleep
    
    ; Since we were in sleep, we need to manually check for a timeout
    btfsc nTO 
    goto rx_reset
    
    reset
    
    end por_vec

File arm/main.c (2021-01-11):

#include <signal.h>
#include <stdbool.h>
#include <stdio.h>
#include <stdlib.h>
#include <math.h>
#include <cblas.h>
#include <string.h>

#include "util.h"
#include "capture.h"
#include "freq.h"
#include "gauge.h"
#include "vrb.h"


#define ACLEN 2048
#define POWER_THRESHOLD 64


static CaptureContext *capture = NULL;
static GaugeContext *gauge = NULL;



static void cleanup()
{
    putchar('\n'); // after the \r from consume()

    if (capture)
        capture_deinit(&capture);

    if (gauge)
        gauge_deinit(&gauge);
}


static void handle_sigint(int signal)
{
    exit(0); // will call cleanup anyway
}


static void consume(CaptureContext *cc, const sample_t *restrict samples, void *p)
{
    VRB *b = p;
    float *restrict present = b->present;
    unsigned N = capture_period(cc);
    for (unsigned i = 0; i < N; i++)
        present[i] = samples[i];
    vrb_advance(b, N*sizeof(float));
}
// Returns the power of the last capture, which will always be needed.
static float read_audio(CaptureContext *cc, VRB *b)
{
    capture_do_capture(cc, consume, b);

    unsigned N = capture_period(cc);
    float *last_cap = vrb_past(b, N*sizeof(float));
    return cblas_sdot(
        N,         // len
        last_cap,  // x
        1,         // incX
        last_cap,  // y
        1          // incY
    )/N;
}

static float power_to_db(float power)
{
    return clip((log10f(power) - 2)/5);
}

int main(int argc, const char **argv)
{
    if (atexit(cleanup))
    {
        perror("Failed to register deinit");
        exit(-1);
    }
    signal(SIGINT, handle_sigint);

    capture = capture_init();
    unsigned period = capture_period(capture);
    gauge = gauge_init();

    //gauge_demo(gauge);

    unsigned hist_len = ACLEN + period;
    VRB *hist = vrb_create(hist_len*sizeof(float));
    float ac[ACLEN];

    while (true)
    {
        float power;
continue_outer_while:
        power = read_audio(capture, hist);
        printf("%f %f\n", power, power_to_db(power));
        gauge_message(gauge, power_to_db(power), 0, 0, 0);
        if (power > POWER_THRESHOLD)
        {
            /*
            There is a note. Load the history buffer with mid-note audio data.
            (The note start is overwritten because it contains transients that
            mess with the reading.)
            */
            unsigned i = 0;
            while (true)
            {
                power = read_audio(capture, hist);
                i += period;
                if (power < POWER_THRESHOLD)
                {
                    printf("%f %f\n", power, power_to_db(power));
                    gauge_message(gauge, power_to_db(power), 0, 0, 0);
                    goto continue_outer_while;
                }
                if (i >= hist_len)
                    break;
                printf("%f %f\n", power, power_to_db(power));
                gauge_message(gauge, power_to_db(power), 0, 0, 0);
            }

            memset(ac, 0, sizeof(ac));
            while (true)
            {
                autocorrelate(vrb_past(hist, hist_len*sizeof(float)), hist_len,
                              ac, ACLEN);
                float f = freq(ac, ACLEN, capture_rate(capture));
                float octave = 0, semitone = 0, deviation = 0;
                if (f > 0)
                {
                    octave = log2f(f/C0);
                    semitone = mod1rd(octave + 1./24);
                    deviation = mod1rd(12*semitone);

                    octave = clip(octave/8);
                }
                printf(
                    "%f %f    %f %f %f %f\n",
                    power,
                    f,
                    power_to_db(power),
                    octave,
                    semitone,
                    deviation
                );
                gauge_message(
                    gauge,
                    power_to_db(power),
                    octave,
                    semitone,
                    deviation
                );

                power = read_audio(capture, hist);
                if (power < POWER_THRESHOLD)
                {
                    printf("%f %f\n", power, power_to_db(power));
                    gauge_message(gauge, power_to_db(power), 0, 0, 0);
                    break;
                }
            }
            //save(ac, sizeof(ac), "data/ac.bin");
        }
    }


    exit(1);
    return 255;
}

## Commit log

2020-10-05 Switch to ALSA
2020-10-05 Explicitly include device number in pcm open call
2020-10-06 Show current element values
2020-10-06 Fix the double free
    [main.c]
2020-10-11 Initialize max_int, though it will not matter in our case
2020-10-12 Use default device instead of enumerating; float conversion yields all 0 so far
2020-10-12 Switch back to mmap s16; try out some BLAS which does not work
2020-10-12 Next is a calibration aide
2020-10-20 Basic assembling, link and program
2020-10-21 PPS, SPI and opamp init
2020-10-23 Initial schematic for DAC
    [dac.brd, dac.sch]
2020-10-23 Switch to high-voltage programming
2020-10-30 Add fade circuit and a little firmware
    [dac.brd, dac.sch]
2020-10-30 Start timer 2
2020-11-24 PWM beat frequency works great; COG has trouble somehow related to input PWM duty cycle
2020-11-25 Fade-in complete - timer interrupt works
2020-11-25 Add image of fading test circuit
2020-11-26 Increase LED drive current to 13mA
    [dac.brd, dac.sch]
2020-11-27 Protoboard layout & routing
    [dac.brd, dac.sch]
2020-11-29 Add an (untested) implementation for SPI receiver
2020-12-05 Journal - SPI stuff
2020-12-05 Notes on diffusion angle and lighting
    [dac.brd, dac.sch]
2020-12-06 Draft SPI parent code; will not compile yet
2020-12-06 Compilation for SPI cleaned up
2020-12-13 MISO pullup, minor cleanup
    [dac.brd, dac.sch]
2020-12-13 Fix polarity of MSSP
    [main.asm]
2020-12-13 Add note about high driving
    [dac.sch]
2020-12-13 Simulation of SPI clock Schmitt trigger
    [spi-clock-st.sch]
2020-12-19 Drop FET driver for LEDs; switch to HIDRV on B0 in open-drain mode; LEDs in serial
    [dac.brd, dac.sch]
2020-12-19 Get closer to 30mA based on a parallel approximation; parts on hand and whatnot
    [dac.brd, dac.sch]
2020-12-21 Ended up using 1k for power indicator; journal entry
    [dac.brd, dac.sch]
2020-12-31 Refactoring pass; currently segfaults in matplotlib draw
2021-01-11 stropts.h is deprecated. Switching to sys/ioctl.h.
2021-01-11 Switched to armpl.
2021-01-11 Added mod1rd_test and vrb_test to arm/.gitignore.
2021-01-11 A first volley at reimplementing the frequency determination code.
    - Autocorrelation is now time-averaged using a VRB.
    - Nuked the old, mostly broken frequency determination code.
    - The audio capture history and autocorrelation accumulation are now managed in
    main.c. The main peak finding still occurs in freq.c. The autocorrelation
    array and sample rate are passed as inputs.
    - Autocorrelation snapshots are now saved in raw binary format. (It is actually
    very easy to load such files in numpy. You just use numpy.fromfile. And what
    kind of edge lord uses big endian architecture these days?)
    [main.c]
2021-01-11 Turned on gauges, fixed a db<->octave mixup, adjusted POWER_THRESHOLD.
    [gauge.c, main.c]
2021-01-11 Resolved some double gauge message sends in the state code.
    [main.c]
2024-06-01 Temporarily cut out alternative parameter structures
2024-06-02 Add bias current
2024-06-03 Add continuous printing
2024-06-03 Add bias to high case; add pullup constraint
2024-07-01 New layout with larger board and level shifter
    [dac.brd, dac.sch]
2024-07-01 Final modifications to level_shifter - restore support for continuous case
2024-07-01 MISO protection network, lower capacitance values, split jumper for LEDs
    [dac.brd, dac.sch]
2024-07-01 Replace screw terminals with more header
    [dac.brd, dac.sch]
2024-07-01 Update pack to 1.7.242. Add debug and release configurations. Add preliminary support for psect optimisation flags. Add comments on bank values. Convert to WPU for unused inputs. ST input levels thro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
2024-07-01 Switch back from simulator to PICkit
2024-07-01 Switch to analogue for unused pins
2024-08-04 Used different protection diodes for LEDs
    [dac.brd, dac.sch]
2024-08-05 Do not pull MISO to 5V
